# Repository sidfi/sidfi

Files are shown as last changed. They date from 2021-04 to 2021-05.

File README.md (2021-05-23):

# SIDfi

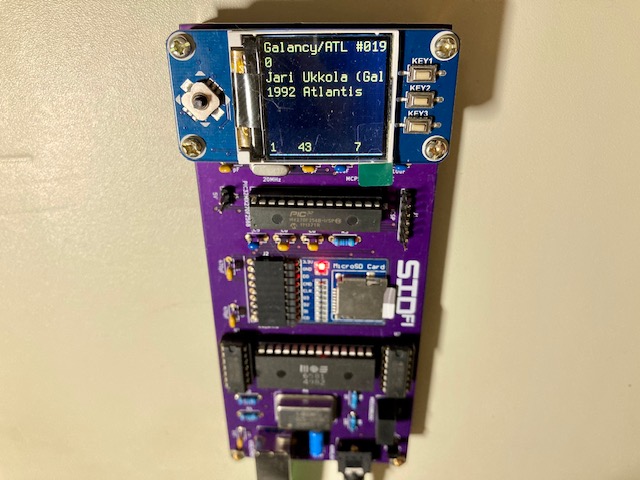
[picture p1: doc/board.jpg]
Board


SIDfi is a single-board self-contained SID file player. SIDfi requires the original MOS 6581 chip or a pin-compatible replacement such as [ARMSID](https://www.nobomi.cz/8bit/armsid/index_en.php). SIDfi plays tune files such as [High Voltage SID Collection](https://hvsc.c64.org/) from a FAT-formatted memory card and displays current tune information on a small LCD screen. Buttons on the LCD screen can be used to control the playback.

## Design Notes

- Emulates MOS 6502 on PIC32MX270F256 microcontroller using [MOS6502 library](https://github.com/gianlucag/mos6502);
- Firmware built with Microchip MPLAB v5.45 and XC32 v2.50;
- [Waveshare 1.44inch LCD HAT](https://www.waveshare.com/1.44inch-lcd-hat.htm) and [ST7735S library](https://github.com/bersch/ST7735S) for display and control;
- [Waveshare Micro SD Storage Board](https://www.waveshare.com/micro-sd-storage-board.htm) and [FatFs library](http://www.elm-chan.org/fsw/ff/00index_e.html) for memory card support;
- 2N3904 transistor for audio amplifier;
- Standard 3mm headset jack for audio output;
- USB 2.0 Type-B connector for 5V power supply (consumes 300mA).

## Schematics

Schematics

## PCB rendering

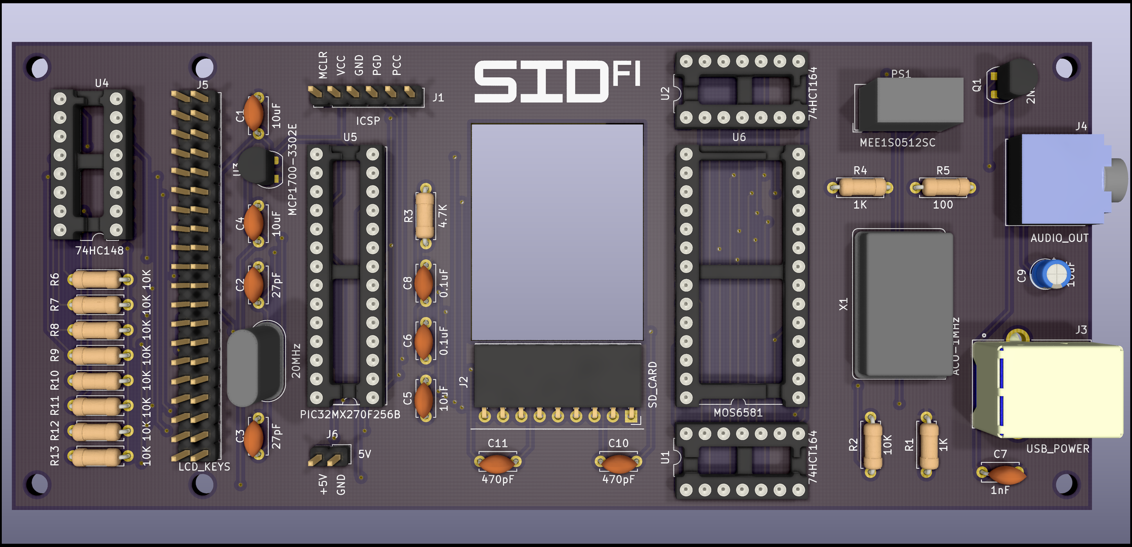
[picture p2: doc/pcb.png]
PCB


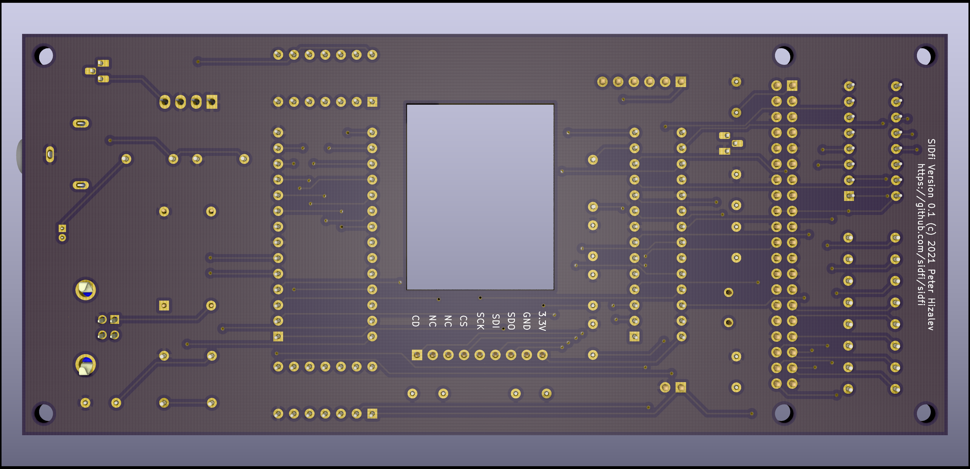
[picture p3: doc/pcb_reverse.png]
PCB reverse


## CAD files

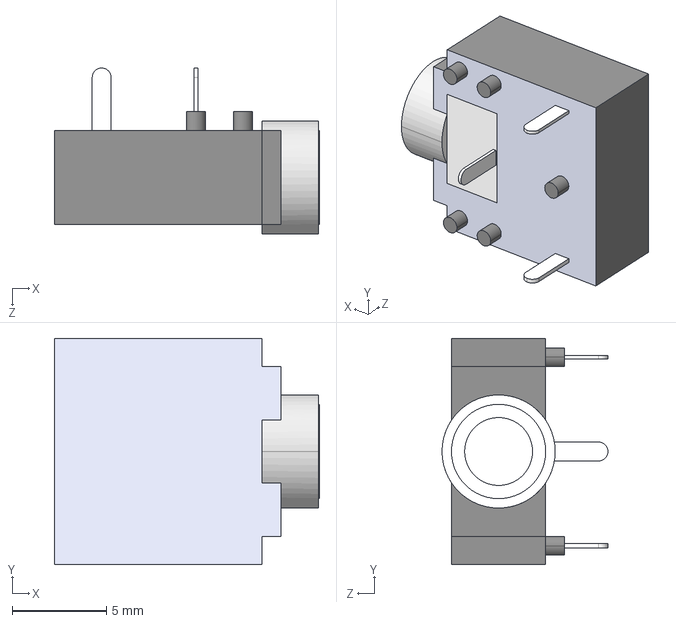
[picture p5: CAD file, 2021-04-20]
hardware/sidfi/3d/CUI_DEVICES_SJ1-3523NG.step
14.0 x 12.0 x 8.80 mm

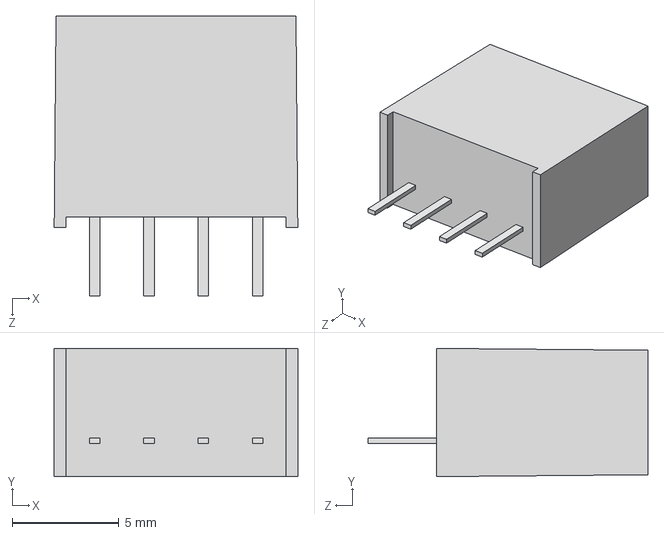
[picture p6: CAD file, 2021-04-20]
hardware/sidfi/3d/tme_3d_drawing.stp
11.4 x 6.00 x 13.1 mm
TME Series
TME PIN x 4

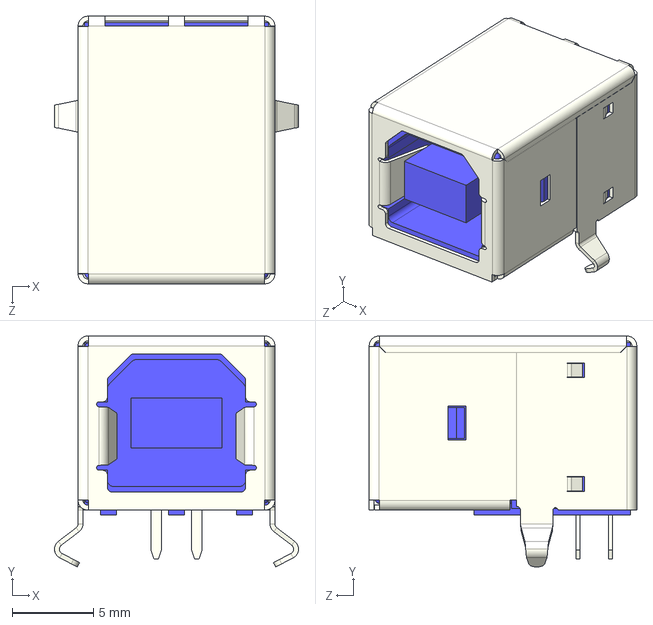
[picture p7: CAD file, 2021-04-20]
hardware/sidfi/3d/CUI_DEVICES_UJ2-BH-BL1-TH.step
15.0 x 14.2 x 16.5 mm

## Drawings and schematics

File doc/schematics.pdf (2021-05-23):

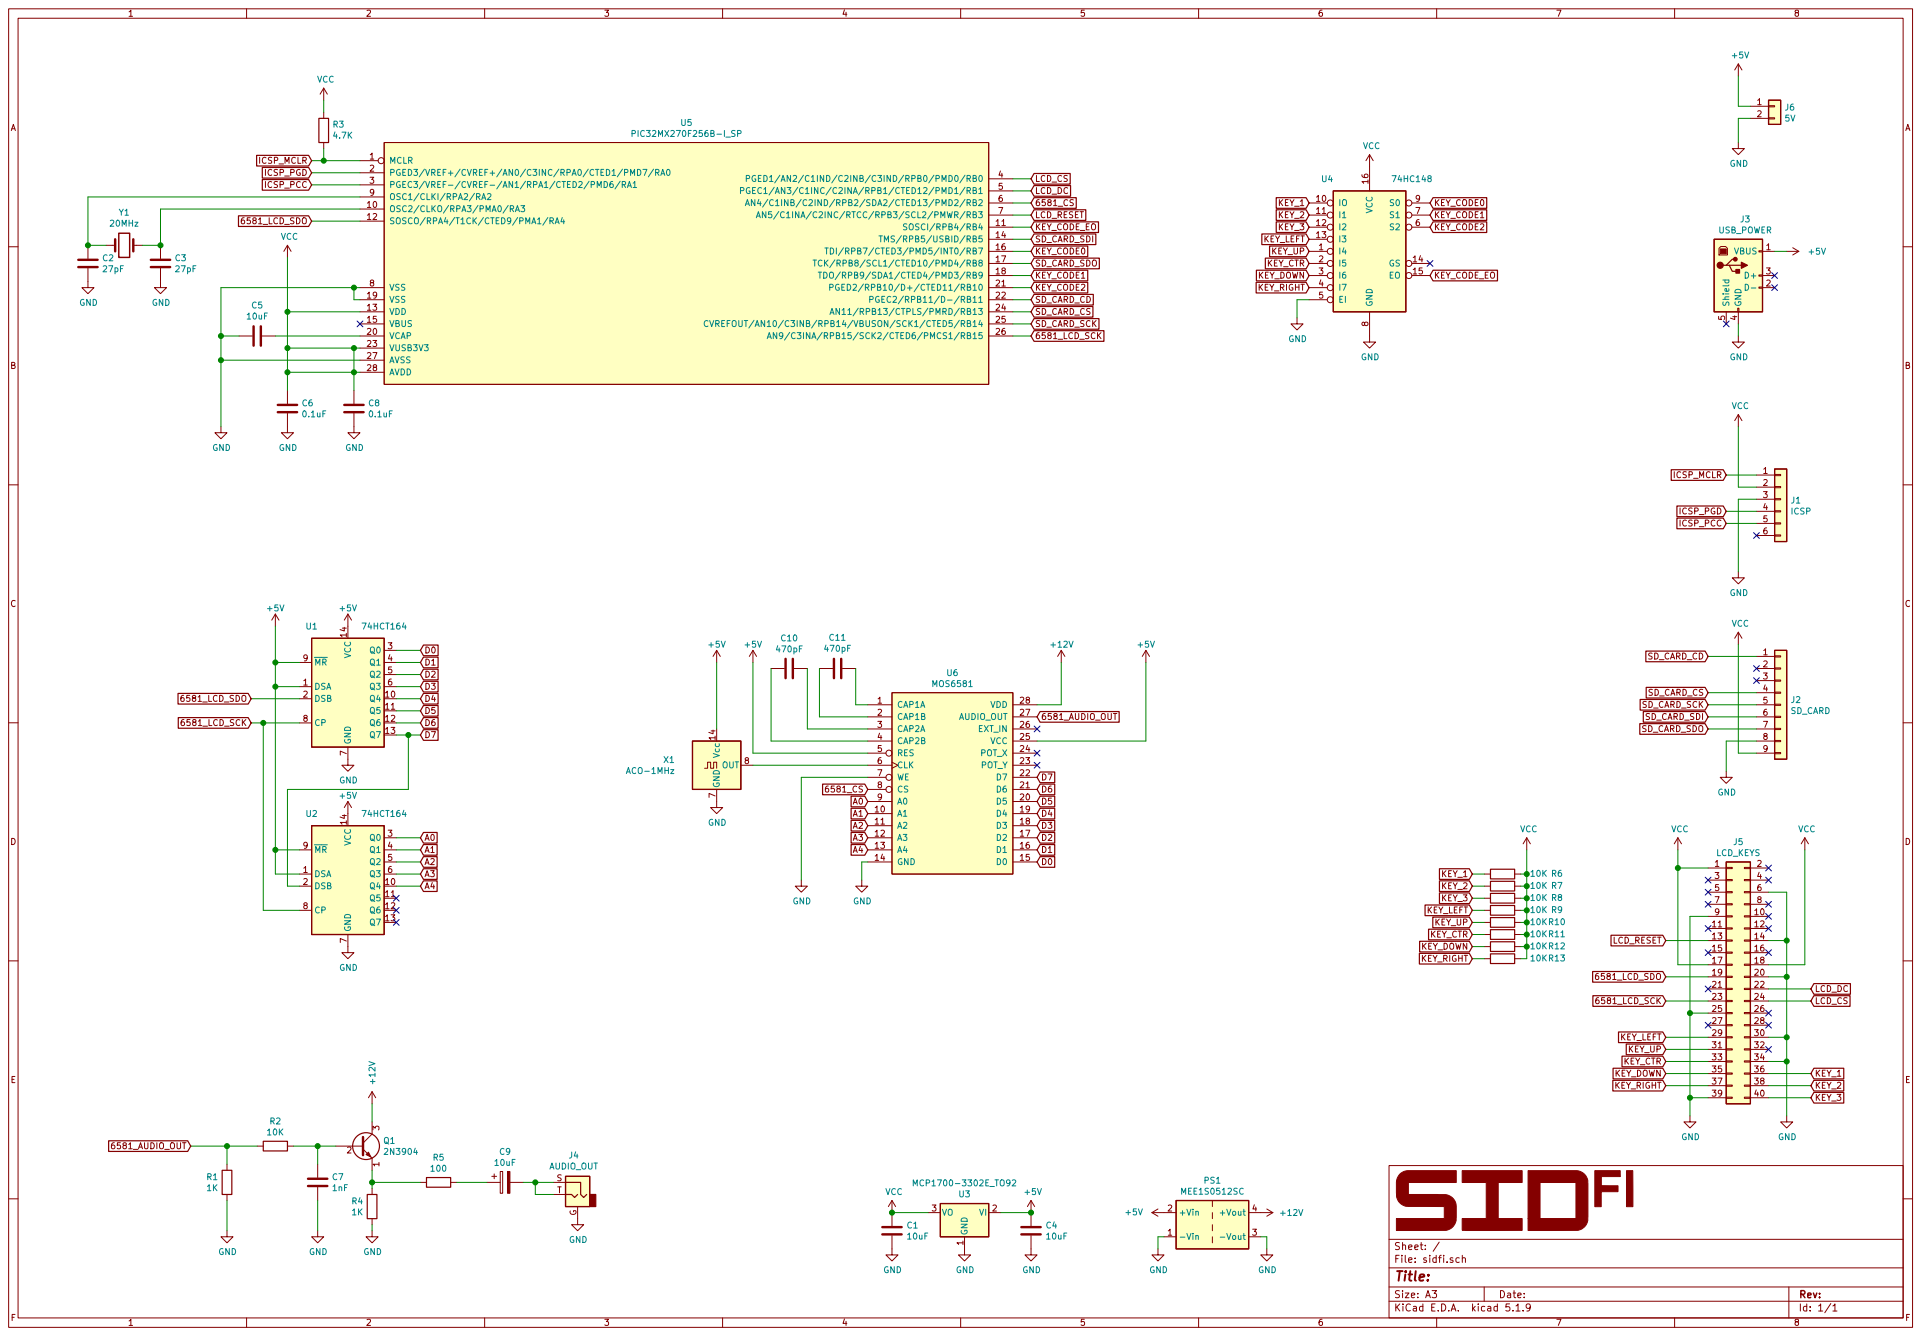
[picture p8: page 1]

7 OUT X1 8 ACO-1MHz GND GND

7 CP 8 MR 9U1 74HCT164 CAP1A 1 A1 10 A2 11 A3 12 A4 13 GND 14 D0 15 D1 16 D2 17 D3 18 D4 19 CAP1B 2 D5 20 D6 21 D7 22 POT_Y 23 POT_X 24 VCC 25 EXT_IN 26 AUDIO_OUT 27 VDD 28 CAP2A 3 CAP2B 4 RES 5 CLK 6 WE 7 CS 8 A0 9 U6 MOS6581

Id: 1/1 Title: File: sidfi.sch Sheet: / G

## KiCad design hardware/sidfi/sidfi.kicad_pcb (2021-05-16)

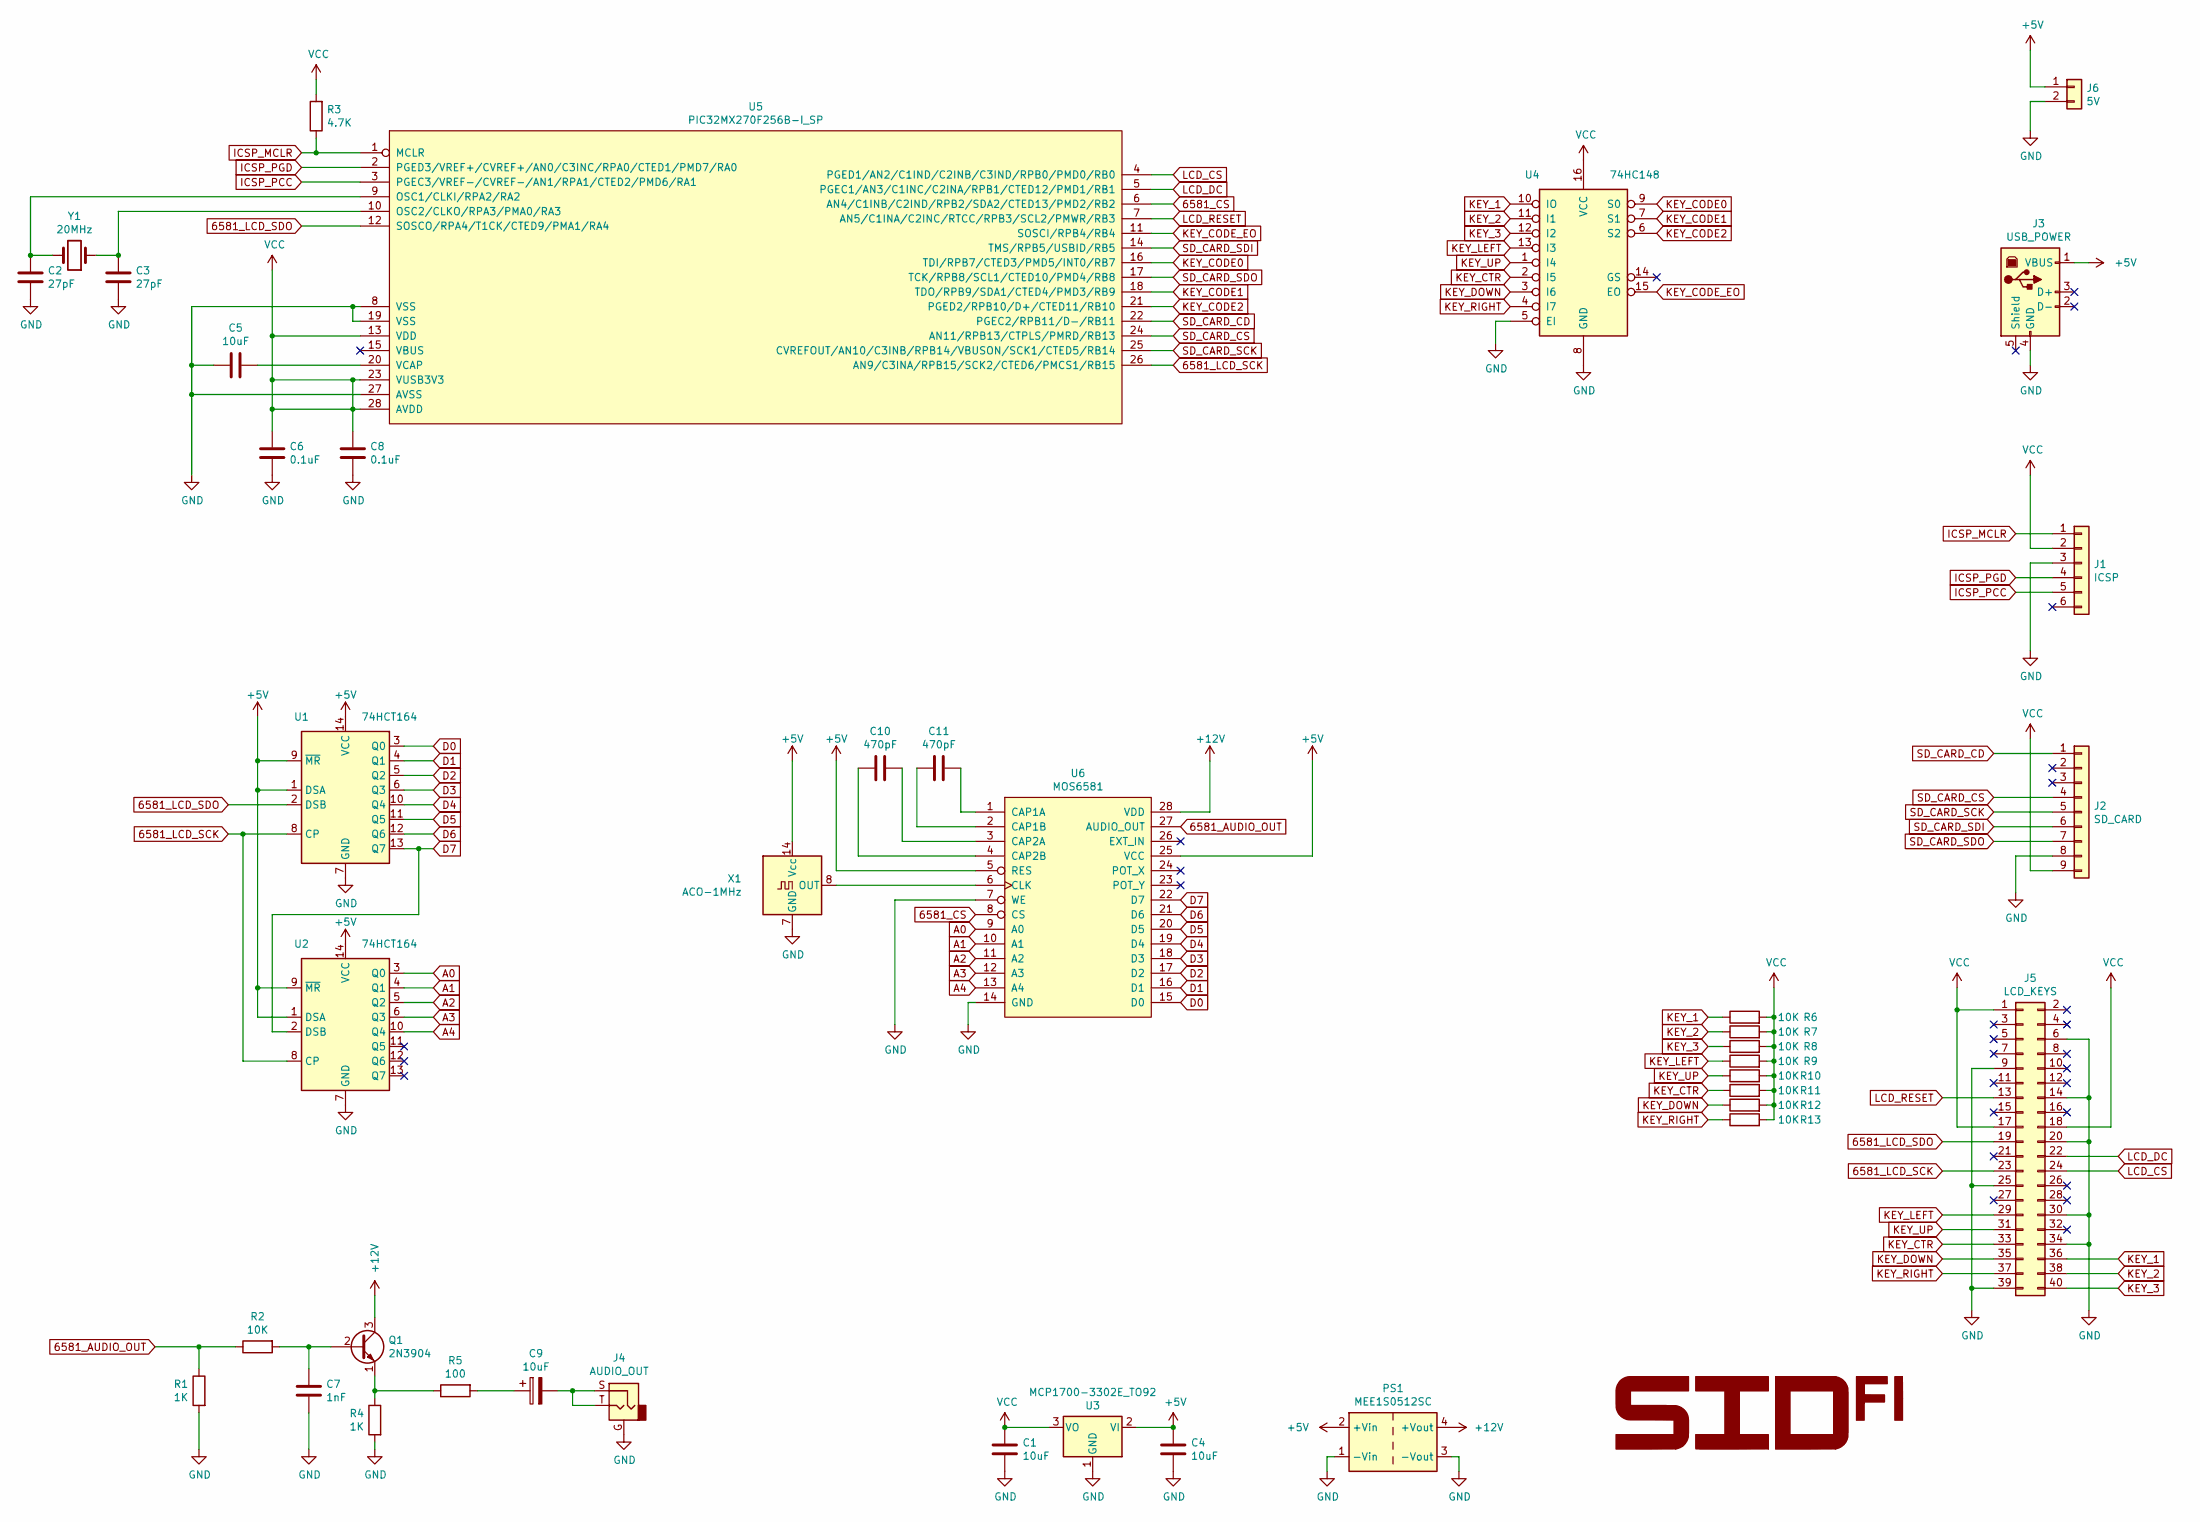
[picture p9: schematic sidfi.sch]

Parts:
C1, C4, C5: 10uF; C_Disc_D5.0mm_W2.5mm_P5.00mm
C2, C3: 27pF; C_Disc_D5.0mm_W2.5mm_P5.00mm
C6, C8: 0.1uF; C_Disc_D5.0mm_W2.5mm_P5.00mm
C7: 1nF; C_Disc_D5.0mm_W2.5mm_P5.00mm
C9: 10uF; CP_Radial_D4.0mm_P1.50mm
C10, C11: 470pF; C_Disc_D5.0mm_W2.5mm_P5.00mm
J1: ICSP; PinHeader_1x06_P2.54mm_Vertical
J2: SD_CARD; PinSocket_1x09_P2.54mm_Horizontal
J3: USB_POWER; CUI_UJ2-BH-1-TH
J4: AUDIO_OUT; CUI_SJ1-3523NG
J5: LCD_KEYS; PinHeader_2x20_P2.54mm_Vertical
J6: 5V; PinHeader_1x02_P2.54mm_Vertical
PS1: MEE1S0512SC; Converter_DCDC_Murata_MEE1SxxxxSC_THT
Q1: 2N3904; TO-92_HandSolder
R1, R4: 1K; R_Axial_DIN0207_L6.3mm_D2.5mm_P7.62mm_Horizontal
R2, R6, R7, R8, R9, R10, R11, R12, R13: 10K; R_Axial_DIN0207_L6.3mm_D2.5mm_P7.62mm_Horizontal
R3: 4.7K; R_Axial_DIN0207_L6.3mm_D2.5mm_P7.62mm_Horizontal
R5: 100; R_Axial_DIN0207_L6.3mm_D2.5mm_P7.62mm_Horizontal
U1, U2: 74HCT164; DIP-14_W7.62mm
U3: MCP1700-3302E_TO92; TO-92_HandSolder
U4: 74HC148; DIP-16_W7.62mm
U5: PIC32MX270F256B-I_SP; DIP-28_W7.62mm_Socket
U6: MOS6581; DIP-28_W15.24mm
X1: ACO-1MHz; Oscillator_DIP-14
Y1: 20MHz; Crystal_HC49-U_Vertical

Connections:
6581_AUDIO_OUT: R1.1, R2.1, U6.27 (AUDIO_OUT)
6581_CS: U5.6 (AN4/C1INB/C2IND/RPB2/SDA2/CTED13/PMD2/R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), U6.8 (CS)
6581_LCD_SCK: J5.23, U1.8 (CP), U2.8 (CP), U5.26 (AN9/C3INA/RPB15/SCK2/CTED6/PMCS1/RB15)
6581_LCD_SDO: J5.19, U1.2 (DSB), U5.12 (SOSCO/RPA4/T1CK/CTED9/PMA1/RA4)
+5V: C4.1, J3.1 (VBUS), J6.1, PS1.2 (+Vin), U1.1 (DSA), U1.9 (~MR), U1.14 (VCC), U2.1 (DSA), U2.9 (~MR), U2.14 (VCC), U3.2 (VI), U6.5 (RES), U6.25 (VCC), X1.14 (Vcc)
+12V: PS1.4 (+Vout), Q1.3 (C), U6.28 (VDD)
A0: U2.3 (Q0), U6.9 (A0)
A1: U2.4 (Q1), U6.10 (A1)
A2: U2.5 (Q2), U6.11 (A2)
A3: U2.6 (Q3), U6.12 (A3)
A4: U2.10 (Q4), U6.13 (A4)
D0: U1.3 (Q0), U6.15 (D0)
D1: U1.4 (Q1), U6.16 (D1)
D2: U1.5 (Q2), U6.17 (D2)
D3: U1.6 (Q3), U6.18 (D3)
D4: U1.10 (Q4), U6.19 (D4)
D5: U1.11 (Q5), U6.20 (D5)
D6: U1.12 (Q6), U6.21 (D6)
D7: U1.13 (Q7), U2.2 (DSB), U6.22 (D7)
GND: C1.2, C2.2, C3.2, C4.2, C5.2, C6.2, C7.2, C8.2, J1.3, J2.8, J3.4 (GND), J4.G, J5.6, J5.9, J5.14, J5.20, J5.25, J5.30, J5.34, J5.39, J6.2, PS1.1 (-Vin), PS1.3 (-Vout), R1.2, R4.2, U1.7 (GND), U2.7 (GND), U3.1 (GND), U4.5 (EI), U4.8 (GND), U5.8 (VSS), U5.19 (VSS), U5.27 (AVSS), U6.7 (WE), U6.14 (GND), X1.7 (GND)
ICSP_MCLR: J1.1, R3.1, U5.1 (MCLR)
ICSP_PCC: J1.5, U5.3 (PGEC3/VREF-/CVREF-/AN1/RPA1/CTED2/PMD6/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)
ICSP_PGD: J1.4, U5.2 (PGED3/VREF+/CVREF+/AN0/C3INC/RPA0/CTED1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)
KEY_1: J5.36, R6.1, U4.10 (IO)
KEY_2: J5.38, R7.1, U4.11 (I1)
KEY_3: J5.40, R8.1, U4.12 (I2)
KEY_CODE0: U4.9 (S0), U5.16 (TDI/RPB7/CTED3/PMD5/INT0/RB7)
KEY_CODE1: U4.7 (S1), U5.18 (TDO/RPB9/SDA1/CTED4/PMD3/RB9)
KEY_CODE2: U4.6 (S2), U5.21 (PGED2/RPB10/D+/CTED11/RB10)
KEY_CODE_EO: U4.15 (EO), U5.11 (SOSCI/RPB4/RB4)
KEY_CTR: J5.33, R11.1, U4.2 (I5)
KEY_DOWN: J5.35, R12.1, U4.3 (I6)
KEY_LEFT: J5.29, R9.1, U4.13 (I3)
KEY_RIGHT: J5.37, R13.1, U4.4 (I7)
KEY_UP: J5.31, R10.1, U4.1 (I4)
LCD_CS: J5.24, U5.4 (PGED1/AN2/C1IND/C2INB/C3IND/RPB0/PMD0/R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)
LCD_DC: J5.22, U5.5 (PGEC1/AN3/C1INC/C2INA/RPB1/CTED12/PMD1/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)
LCD_RESET: J5.13, U5.7 (AN5/C1INA/C2INC/RTCC/RPB3/SCL2/PMWR/RB3)
unnamed: C2.1, U5.9 (OSC1/CLKI/RPA2/RA2), Y1.2
unnamed: C3.1, U5.10 (OSC2/CLKO/RPA3/PMA0/RA3), Y1.1
unnamed: C5.1, U5.20 (VCAP)
unnamed: C7.1, Q1.2 (B), R2.2
unnamed: C9.1, R5.2
unnamed: C9.2, J4.S, J4.T
unnamed: C10.1, U6.3 (CAP2A)
unnamed: C10.2, U6.4 (CAP2B)
unnamed: C11.1, U6.2 (CAP1B)
unnamed: C11.2, U6.1 (CAP1A)
unnamed: Q1.1 (E), R4.1, R5.1
unnamed: U6.6 (CLK), X1.8 (OUT)
SD_CARD_CD: J2.1, U5.22 (PGEC2/RPB11/D-/RB11)
SD_CARD_CS: J2.4, U5.24 (AN11/RPB13/CTPLS/PMRD/RB13)
SD_CARD_SCK: J2.5, U5.25 (CVREFOUT/AN10/C3INB/RPB14/VBUSON/SCK1/C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)
SD_CARD_SDI: J2.6, U5.14 (TMS/RPB5/USBID/RB5)
SD_CARD_SDO: J2.7, U5.17 (TCK/RPB8/SCL1/CTED10/PMD4/RB8)
VCC: C1.1, C6.1, C8.1, J1.2, J2.9, J5.1, J5.17, J5.18, R3.2, R6.2, R7.2, R8.2, R9.2, R10.2, R11.2, R12.2, R13.2, U3.3 (VO), U4.16 (VCC), U5.13 (VDD), U5.23 (VUSB3V3), U5.28 (AVDD)

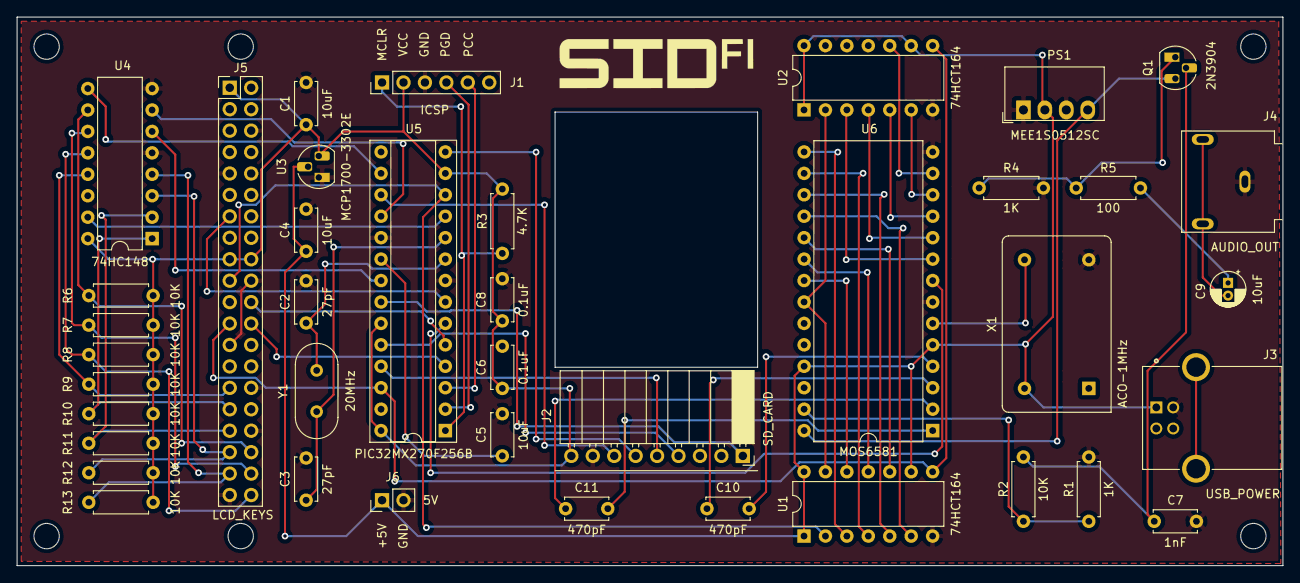
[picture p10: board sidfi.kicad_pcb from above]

Board: 2 copper layers, 150.0 x 65.0 mm, 40 parts (0 on the bottom side), 56 nets.

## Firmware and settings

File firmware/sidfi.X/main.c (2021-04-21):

#include "config.h"

#define _DISABLE_OPENADC10_CONFIGPORT_WARNING
#define _SUPPRESS_PLIB_WARNING
#include <plib.h>

#include <stdbool.h>
#include <stdint.h>
#include <stdlib.h>
#include <string.h>

#include "cpu.h"
#include "diskio.h"
#include "ff.h"
#include "st7735s.h"

#include "fonts.h"
#include "gfx.h"

#define CLOCKFREQ (50000000ul)  // This is set in in Configuration Bits.h
#define BUSFREQ (CLOCKFREQ / 1) // This is set in in Configuration Bits.h

#define nsleep(ns)                                                             \
  {                                                                            \
    uint32_t c =                                                               \
        ReadCoreTimer() + (((uint32_t)(ns)) / (2000000000 / CLOCKFREQ));       \
    while (ReadCoreTimer() < c)                                                \
      ;                                                                        \
  }
#define halt()                                                                 \
  {                                                                            \
    while (1)                                                                  \
      ;                                                                        \
  }

#define MEMORY_VIRTUAL_PAGE_NUMBER 64
#define MEMORY_PHYSICAL_PAGE_NUMBER 48
#define MEMORY_PAGE_SIZE 1024
#define MEMORY_PAGE_BITS 10
#define MEMORY_PAGE_MASK 0x3ff
#define MEMORY_UNALLOCATED_PAGE_NUMBER UINT16_MAX

uint16_t memory_page_table[MEMORY_VIRTUAL_PAGE_NUMBER];
uint8_t memory[MEMORY_PHYSICAL_PAGE_NUMBER * MEMORY_PAGE_SIZE];
uint8_t memory_free_page = 0;

void memory_init() {
  for (size_t i = 0; i < MEMORY_VIRTUAL_PAGE_NUMBER; ++i)
    memory_page_table[i] = MEMORY_UNALLOCATED_PAGE_NUMBER;
}

static bool memory_virtual_to_physical(uint16_t v_address,
                                       uint16_t *p_address) {
  size_t i = v_address >> MEMORY_PAGE_BITS;
  size_t p = memory_page_table[i];

  if (p == MEMORY_UNALLOCATED_PAGE_NUMBER) {
    if (memory_free_page == MEMORY_PHYSICAL_PAGE_NUMBER)
      return false;

    memory_page_table[i] = p = memory_free_page;
    memory_free_page++;
  }

  *p_address = (p << MEMORY_PAGE_BITS) | (v_address & MEMORY_PAGE_MASK);
  return true;
}

static bool memory_write(uint16_t address, uint8_t data) {
  bool res = memory_virtual_to_physical(address, &address);
  if (res)
    memory[address] = data;
  return res;
}

static uint8_t memory_read(uint16_t address) {
  bool res = memory_virtual_to_physical(address, &address);
  return res ? memory[address] : 0;
}

static bool is_mos6581_address(uint16_t address) {
  return address >= 0xD400 && address < 0xD800;
}

static void mos6581_write(uint8_t address, uint8_t data) {
  SPI2BUF = address;
  while (SPI2STATbits.SPIBUSY)
    ;

  SPI2BUF = data;
  while (SPI2STATbits.SPIBUSY)
    ;

  _LATB2 = 0;
  nsleep(5000);
  _LATB2 = 1;
}

void cpu_memory_write(uint16_t address, uint8_t data) {
  if (is_mos6581_address(address)) {
    mos6581_write(address & 0x1f, data);
  } else {
    memory_write(address, data);
  }
}

uint8_t cpu_memory_read(uint16_t address) {
  if (is_mos6581_address(address)) {
    return 0;
  }

  return memory_read(address);
}

#define PSID_MIN_HEADER_LENGTH 118 // Version 1
#define PSID_MAX_HEADER_LENGTH 124 // Version 2

// Offsets of fields in header (all fields big-endian)
enum {
  PSID_MAGIC_ID = 0,   // 'PSID'
  PSID_VERSION = 4,    // 1 or 2
  PSID_LENGTH = 6,     // Header length
  PSID_LOAD = 8,       // C64 load address
  PSID_INIT = 10,      // C64 init routine address
  PSID_PLAY = 12,      // C64 replay routine address
  PSID_NUMBER = 14,    // Number of subsongs
  PSID_DEFSONG = 16,   // Main subsong number
  PSID_SPEED = 18,     // Speed flags (1 bit/song)
  PSID_NAME = 22,      // Module name (ISO Latin1 character set)
  PSID_AUTHOR = 54,    // Author name (dto.)
  PSID_COPYRIGHT = 86, // Copyright info (dto.)
  PSID_FLAGS = 118,    // Flags (only in version 2 header)
  PSID_RESERVED = 120
};

enum sid_result {
  SIDFILE_OK,
  SIDFILE_ERROR_IO,
  SIDFILE_ERROR_MALFORMED,
  SIDFILE_ERROR_TOOBIG
};

struct sid {
  const char *module_name;
  const char *author_name;
  const char *copyright_info;
  size_t num_of_songs;
  size_t first_song;
  uint16_t init_address;
  uint16_t play_address;
  uint16_t load_address;
  uint32_t speed_flags;
};

static uint16_t read_uint16(const uint8_t *data, uint16_t offset) {
  return (data[offset] << 8) | data[offset + 1];
}

static uint32_t read_uint32(const uint8_t *data, uint16_t offset) {
  return (data[offset] << 24) | (data[offset + 1] << 16) |
         (data[offset + 2] << 8) | data[offset + 3];
}

static bool is_header(const uint8_t *data) {
  uint32_t magic_id = read_uint32(data, PSID_MAGIC_ID);
  uint16_t version = read_uint16(data, PSID_VERSION);
  return magic_id == 0x50534944 && (version == 1 || version == 2);
}

#define SID_READ_BUFFER_SIZE 512
uint8_t sid_read_buffer[SID_READ_BUFFER_SIZE];

enum sid_result sid_read_file(struct sid *sid, const TCHAR *file_path) {
  FIL f;
  FRESULT fr = f_open(&f, file_path, FA_READ);
  if (fr != FR_OK) {
    return SIDFILE_ERROR_IO;
  }

  UINT read;
  static uint8_t sid_header[PSID_MAX_HEADER_LENGTH];
  fr = f_read(&f, sid_header, PSID_MAX_HEADER_LENGTH, &read);

  if (fr != FR_OK) {
    f_close(&f);
    return SIDFILE_ERROR_IO;
  }

  if (read < PSID_MIN_HEADER_LENGTH || !is_header(sid_header)) {
    f_close(&f);
    return SIDFILE_ERROR_MALFORMED;
  }

  sid->num_of_songs = read_uint16(sid_header, PSID_NUMBER);

  if (sid->num_of_songs == 0) {
    sid->num_of_songs = 1;
  }

  sid->first_song = read_uint16(sid_header, PSID_DEFSONG);
  if (sid->first_song) {
    sid->first_song--;
  }
  if (sid->first_song >= sid->num_of_songs) {
    sid->first_song = 0;
  }

  sid->init_address = read_uint16(sid_header, PSID_INIT);
  sid->play_address = read_uint16(sid_header, PSID_PLAY);
  sid->speed_flags = read_uint32(sid_header, PSID_SPEED);

  sid->module_name = (const char *)(sid_header + PSID_NAME);
  sid->author_name = (const char *)(sid_header + PSID_AUTHOR);
  sid->copyright_info = (const char *)(sid_header + PSID_COPYRIGHT);

  FSIZE_t dataOffset = read_uint16(sid_header, PSID_LENGTH);
  fr = f_lseek(&f, dataOffset);

  if (fr != FR_OK) {
    f_close(&f);
    return SIDFILE_ERROR_IO;
  }

  // Find load address

  sid->load_address = read_uint16(sid_header, PSID_LOAD);
  if (sid->load_address == 0) {
    uint8_t lo, hi;
    fr = f_read(&f, &lo, 1, &read);
    if (fr != FR_OK) {
      f_close(&f);
      return SIDFILE_ERROR_IO;
    }

    fr = f_read(&f, &hi, 1, &read);
    if (fr != FR_OK) {
      f_close(&f);
      return SIDFILE_ERROR_IO;
    }

    sid->load_address = (hi << 8) | lo;
  }

  if (sid->init_address == 0) {
    sid->init_address = sid->load_address;
  }

  size_t address = sid->load_address;

  do {
    fr = f_read(&f, sid_read_buffer, SID_READ_BUFFER_SIZE, &read);

    for (size_t i = 0; i < read; ++i) {
      if (!memory_write(address + i, sid_read_buffer[i]))
        return SIDFILE_ERROR_TOOBIG;
    }

    address += read;

    if (fr != FR_OK) {
      f_close(&f);
      return SIDFILE_ERROR_IO;
    }
  } while (read != 0);

  f_close(&f);
  return SIDFILE_OK;
}

#define SONG_LENGTHS_MAX 16

struct song_lengths {
  size_t num;
  uint32_t ms[SONG_LENGTHS_MAX];
};

#define SONG_LENGTHS_LINE_BUFFER_SIZE 2048

enum song_lengths_res {
  SONG_LENGTHS_FOUND,
  SONG_LENGTHS_NOT_FOUND,
  SONG_LENGTHS_ERROR_IO
};

enum song_lengths_parse_state {
  SONG_LENGTHS_PARSE_STATE_NONE,
  SONG_LENGTHS_PARSE_STATE_MINUTES,
  SONG_LENGTHS_PARSE_STATE_SECONDS,
  SONG_LENGTHS_PARSE_STATE_MS
};

void song_lengths_read_value(struct song_lengths *song_lengths, size_t i,
                             enum song_lengths_parse_state parse_state,
                             uint32_t parse_value) {
  switch (parse_state) {
  case SONG_LENGTHS_PARSE_STATE_MINUTES:
    song_lengths->ms[i] += parse_value * 60000;
    break;
  case SONG_LENGTHS_PARSE_STATE_SECONDS:
    song_lengths->ms[i] += parse_value * 1000;
    break;
  case SONG_LENGTHS_PARSE_STATE_MS:
    song_lengths->ms[i] += parse_value;
    break;
  }
}

#define SONG_LENGTHS_PARSE_VALUE_MAX_DIGITS 3

uint32_t song_lengths_parse_value(
    size_t k, uint32_t parse_digits[SONG_LENGTHS_PARSE_VALUE_MAX_DIGITS]) {
  uint16_t parse_value = 0;
  const uint32_t multiple[SONG_LENGTHS_PARSE_VALUE_MAX_DIGITS] = {1, 10, 100};
  for (size_t i = 0; i < k; i++) {
    parse_value += parse_digits[i] * multiple[k - i - 1];
  }
  return parse_value;
}

enum song_lengths_res
song_lengths_read_line(uint8_t *line, const TCHAR *sid_file_path,
                       struct song_lengths *song_lengths) {
  static int last_strcmp_res = -1;
  if (line[0] == ';') {
    last_strcmp_res = strcmp(&line[2], sid_file_path);
  } else if (last_strcmp_res == 0) {
    last_strcmp_res = -1;

    size_t l = strlen(line);
    size_t k = 0;

    enum song_lengths_parse_state parse_state = SONG_LENGTHS_PARSE_STATE_NONE;
    uint32_t parse_digits[SONG_LENGTHS_PARSE_VALUE_MAX_DIGITS];

    song_lengths->num = 0;
    song_lengths->ms[0] = 0;

    for (size_t i = 0; i < l; i++) {
      if (line[i] == '=') {
        parse_state = SONG_LENGTHS_PARSE_STATE_MINUTES;
        k = 0;
      } else if (parse_state == SONG_LENGTHS_PARSE_STATE_MINUTES &&
                 line[i] == ':') {
        song_lengths_read_value(song_lengths, song_lengths->num, parse_state,
                                song_lengths_parse_value(k, parse_digits));

        parse_state = SONG_LENGTHS_PARSE_STATE_SECONDS;
        k = 0;
      } else if (parse_state == SONG_LENGTHS_PARSE_STATE_SECONDS &&
                 line[i] == '.') {
        song_lengths_read_value(song_lengths, song_lengths->num, parse_state,
                                song_lengths_parse_value(k, parse_digits));

        parse_state = SONG_LENGTHS_PARSE_STATE_MS;
        k = 0;
      } else if (line[i] == ' ') {
        if (song_lengths->num == SONG_LENGTHS_MAX - 1)
          break;

        song_lengths_read_value(song_lengths, song_lengths->num, parse_state,
                                song_lengths_parse_value(k, parse_digits));
        song_lengths->num++;

        song_lengths->ms[song_lengths->num] = 0;

        parse_state = SONG_LENGTHS_PARSE_STATE_MINUTES;
        k = 0;
      } else if (line[i] >= '0' && line[i] <= '9' &&
                 k < SONG_LENGTHS_PARSE_VALUE_MAX_DIGITS) {
        parse_digits[k] = (line[i] - 0x30);
        k++;
      }
    }
    song_lengths_read_value(song_lengths, song_lengths->num, parse_state,
                            song_lengths_parse_value(k, parse_digits));
    song_lengths->num++;

    return SONG_LENGTHS_FOUND;
  }
  return SONG_LENGTHS_NOT_FOUND;
}

#define SONG_LENGTHS_READ_BUFFER_SIZE 512
uint8_t song_lengths_read_buffer[SONG_LENGTHS_READ_BUFFER_SIZE];

FIL song_lengths_file;

void song_lengths_open_file(const TCHAR *song_lengths_file_path) {
  f_open(&song_lengths_file, song_lengths_file_path, FA_READ);
}

enum song_lengths_res
song_lengths_find_in_file(const TCHAR *sid_file_path,
                       struct song_lengths *song_lengths) {
  static uint8_t line_buffer[SONG_LENGTHS_LINE_BUFFER_SIZE];
  static UINT read = 0;

  size_t i = 0;
  FRESULT fr;

  do {
    static size_t k = 0;
    while (k != read) {
      uint8_t c = song_lengths_read_buffer[k++];
      if (c == '\n' || c == '\r' || i == SONG_LENGTHS_LINE_BUFFER_SIZE - 1) {
        if (i == 0)
          continue;

        line_buffer[i] = 0;
        i = 0;

        if (song_lengths_read_line(line_buffer, sid_file_path, song_lengths) ==
            SONG_LENGTHS_FOUND)
          return SONG_LENGTHS_FOUND;
      } else
        line_buffer[i++] = c;
    }

    k = 0;
    fr = f_read(&song_lengths_file, song_lengths_read_buffer, SONG_LENGTHS_READ_BUFFER_SIZE, &read);
    if (fr != FR_OK)
      return SONG_LENGTHS_ERROR_IO;

  } while (read != 0);

  fr = f_lseek(&song_lengths_file, 0);

  if (fr != FR_OK)
    return SONG_LENGTHS_ERROR_IO;

  return SONG_LENGTHS_NOT_FOUND;
}

void sid_init_player(struct sid *sid, uint8_t song_number) {
  // install reset vector for microplayer (0x0000)
  memory_write(0xFFFD, 0x00);
  memory_write(0xFFFC, 0x00);

  // install IRQ vector for play routine launcher (0x0013)
  memory_write(0xFFFF, 0x00);
  memory_write(0xFFFE, 0x13);

  // install the micro player, 6502 assembly code
  memory_write(0x0000, 0xA9); // A = 0, load A with the song number
  memory_write(0x0001, song_number);

  memory_write(0x0002, 0x20);                     // jump sub to INIT routine
  memory_write(0x0003, sid->init_address & 0xFF); // lo addr
  memory_write(0x0004, (sid->init_address >> 8) & 0xFF); // hi addr

  memory_write(0x0005, 0x58); // enable interrupt
  memory_write(0x0006, 0xEA); // nop
  memory_write(0x0007, 0x4C); // jump to 0x0006
  memory_write(0x0008, 0x06);
  memory_write(0x0009, 0x00);

  memory_write(0x0013, 0xEA); // nop  //0xA9; // A = 1
  memory_write(0x0014, 0xEA); // nop //0x01;
  memory_write(0x0015, 0xEA); // 0x78 CLI
  memory_write(0x0016, 0x20); // jump sub to play routine
  memory_write(0x0017, sid->play_address & 0xFF);
  memory_write(0x0018, (sid->play_address >> 8) & 0xFF);
  memory_write(0x0019, 0xEA); // 0x58 SEI
  memory_write(0x001A, 0x40); // RTI: return from interrupt
}

uint32_t sid_song_speed_ns(struct sid *sid, uint8_t song_number) {
  return ((sid->speed_flags >> (song_number % 32)) & 1) ? 16666666 /* 60Hz */
                                                        : 20000000 /* 50Hz */;
}

void __ISR(_TIMER_4_VECTOR, ipl1auto) T4Interrupt(void) {
  disk_timerproc();

  mT4ClearIntFlag();
}

uint32_t next_random() {
  static uint32_t random = 0;
  random += ReadCoreTimer();
  return random;
}

static char traverse_files_buffer[1024];
static size_t traverse_files_dir_index = -1;
static DIR traverse_files_dirs[6];

static FRESULT traverse_files_open_dir() {
  FRESULT res;
  res = f_opendir(&traverse_files_dirs[traverse_files_dir_index + 1],
                  traverse_files_buffer); /* Open the directory */
  if (res != FR_OK)
    return res;

  traverse_files_dir_index++;

  return res;
}

static void traverse_files_close_dir() {
  f_closedir(&traverse_files_dirs[traverse_files_dir_index]);

  traverse_files_dir_index--;
}

static FRESULT traverse_files_next(char **path) {
  FRESULT res;
  FILINFO fno;
  static size_t slash_pos[6];

  if (traverse_files_dir_index == -1) {
    res = traverse_files_open_dir();

    if (res != FR_OK)
      return res;

    slash_pos[traverse_files_dir_index] = -1;

    return traverse_files_next(path);
  }

  if (slash_pos[traverse_files_dir_index] != -1) {
    traverse_files_buffer[slash_pos[traverse_files_dir_index]] = 0;
    slash_pos[traverse_files_dir_index] = -1;
  }

  res = f_readdir(&traverse_files_dirs[traverse_files_dir_index], &fno);
  if (res != FR_OK)
    return res;

  if (!fno.fname[0]) {
    traverse_files_close_dir();

    return traverse_files_next(path);
  }

  size_t l = strlen(traverse_files_buffer);
  slash_pos[traverse_files_dir_index] = l;

  traverse_files_buffer[l] = '/';
  strcpy(&traverse_files_buffer[l + 1], fno.fname);

  if (fno.fattrib & AM_DIR) {
    res = traverse_files_open_dir();

    if (res != FR_OK)
      return res;

    slash_pos[traverse_files_dir_index] = -1;

    return traverse_files_next(path);
  }

  *path = traverse_files_buffer;
  return res;
}

static void traverse_files_init(const char *base_path) {
  while (traverse_files_dir_index != -1) {
    f_closedir(&traverse_files_dirs[traverse_files_dir_index]);
    traverse_files_dir_index--;
  }

  strcpy(traverse_files_buffer, base_path);
}

static uint32_t break_timer0 = 0;
static uint32_t break_timer1 = 0;

static bool set_break_ns(uint32_t ns0, uint32_t ns1) {
  break_timer0 = ns0 / (2000000000 / CLOCKFREQ);
  break_timer1 = ns1 / (2000000000 / CLOCKFREQ);
  WriteCoreTimer(0);
}

static bool should_break0() { return ReadCoreTimer() >= break_timer0; }
static bool should_break1() { return ReadCoreTimer() >= break_timer1; }

char *itoa(int value) {
  static char buffer[12]; // 12 bytes is big enough for an INT32
  int original = value;   // save original value

  int c = sizeof(buffer) - 1;

  buffer[c] = 0; // write trailing null in last byte of buffer

  if (value < 0) // if it's negative, note that and take the absolute value
    value = -value;

  do // write least significant digit of value that's left
  {
    buffer[--c] = (value % 10) + '0';
    value /= 10;
  } while (value);

  if (original < 0)
    buffer[--c] = '-';

  return &buffer[c];
}

static FATFS fs;

#define SCANCODE_NONE 7
#define SCANCODE_RIGHT 8
#define SCANCODE_LEFT 9
#define SCANCODE_CTR 10
#define SCANCODE_KEY2 11
#define SCANCODE_DOWN 12
#define SCANCODE_KEY1 13
#define SCANCODE_UP 14
#define SCANCODE_KEY3 15

int main() {
  ANSELA = 0;
  ANSELB = 0;
  mJTAGPortEnable(0);

  SYSTEMConfigPerformance(CLOCKFREQ);
  mOSCSetPBDIV(OSC_PB_DIV_1);

  LATA = LATB = 0;
  TRISA = TRISB = 0xffffffff;
  CNENA = CNENB = CNCONA = CNCONB = 0;
  CNPUA = CNPUB = CNPDA = CNPDB = 0;

  PR4 = 1000 * (BUSFREQ / 2 / 1000000) - 1;
  T4CON = 0x8010;
  mT4SetIntPriority(1);
  mT4ClearIntFlag();
  mT4IntEnable(1);

  _TRISB2 = 0; _LATB2 = 1;  // MOS 6581 CS        (6)
  PPSOutput(3, RPA4, SDO2); // MOS 6581 / LCD SDO (12)
                            // MOS 6581 / LCD SCK (26)

  _TRISB13 = 0; _LATB13 = 1; // SD CARD CS  (24)
  _TRISB11 = 1;              // SD CARD CD  (22)
  PPSOutput(2, RPB5, SDO1);  // SD CARD SDO (14)
  PPSInput(2, SDI1, RPB8);   // SD CARD SDI (17)
                             // SD CARD SCK (25)

  _TRISB0 = 0; _LATB0 = 1; // LCD CS    (4)
  _TRISB1 = 0; _LATB1 = 1; // LCD DC    (5)
  _TRISB3 = 0; _LATB3 = 0; // LCD RESET (7)

  _TRISB4 = 1;  // KEY CTR   (11)
  _TRISB7 = 1;  // KEY UP    (16)
  _TRISB9 = 1;  // KEY DOWN  (18)
  _TRISB10 = 1; // KEY RIGHT (21)

  INTEnableSystemMultiVectoredInt();
  INTEnableInterrupts();

  nsleep(1000000);

  SpiChnOpen(SPI_CHANNEL2,
             (SpiOpenFlags)(SPI_OPEN_MODE8 | SPI_OPEN_MSTEN | SPI_OPEN_DISSDI |
                            SPI_OPEN_CKE_REV),
             2);

  ST7735S_Init();
  setOrientation(R0);

  f_mount(&fs, "", 0);

  setbgColor(31, 63, 31);
  setFont(ter_u16n);

  memory_init();
  cpu_init(cpu_memory_read, cpu_memory_write);

  traverse_files_init("");
  song_lengths_open_file("/DOCUMENTS/Songlengths.md5");

  next_random();

  struct sid sid;
  struct song_lengths song_lengths;
  
  memset(&sid, 0, sizeof(struct sid));
  memset(&song_lengths, 0, sizeof(struct song_lengths));
  
  uint32_t timer = 0;
  uint8_t song_number = 0;
  uint32_t song_speed_ns = 0;
  uint32_t song_length_ms = 0;
  uint8_t debounce_counter = 0;
  uint8_t prev_scancode = 1;
  enum song_lengths_res slr = 0;

  while (1) {
    if (!timer) {
      if (!sid.num_of_songs || ++song_number == sid.num_of_songs) {
        setColor(31, 63, 31);
        fillScreen();
        setColor(0, 63, 0);
        drawText(0, 0, "Loading...");
        flushBuffer();

        while (1) {
          char *sid_file_path;
          FRESULT fr;
          uint32_t i = next_random() % 10000;          

          while (i--)
            fr = traverse_files_next(&sid_file_path);
            
          if (fr != FR_OK)
            continue;

          enum sid_result sidr = sid_read_file(&sid, sid_file_path);
          if (sidr == SIDFILE_OK) {
            slr = song_lengths_find_in_file(sid_file_path, &song_lengths);
            song_number = 0;
            break;
          }
        }
      }
      song_length_ms =
          ((slr == SONG_LENGTHS_FOUND && song_number < song_lengths.num)
               ? song_lengths.ms[song_number]
               : 60000);
      song_speed_ns = sid_song_speed_ns(&sid, song_number);
      timer = (song_length_ms * 1000) / (song_speed_ns / 1000);

      sid_init_player(&sid, song_number);

      set_break_ns(1000000, 0);
      cpu_reset();
      cpu_run(should_break0);

      setColor(31, 63, 31);
      fillScreen();
      setColor(0, 0, 31);
      uint16_t line = 0;
      /*size_t len = strlen(sid_file_path);
      for (size_t i = 0; i <= len / 16; i++)
        drawText(0, (line++) * 16, sid_file_path + (i * 16));*/
      drawText(0, (line++) * 16, sid.module_name);
      drawText(0, (line++) * 16, itoa(song_number));
      drawText(0, (line++) * 16, sid.author_name);
      drawText(0, (line++) * 16, sid.copyright_info);
      flushBuffer();
    } else
      timer--;

    set_break_ns(song_speed_ns - 4000000, song_speed_ns);
    cpu_irq();
    cpu_run(should_break0);

    uint8_t scancode = (_RB4 << 3) | (_RB7 << 2) | (_RB9 << 1) | _RB10;

    if (scancode != prev_scancode) {
      debounce_counter = 0;
      prev_scancode = scancode;
    } else
      debounce_counter++;

    if (debounce_counter == 3) {
      debounce_counter = 0;

      if (scancode == SCANCODE_KEY1) {
        timer = 0;
        continue;
      }
    }

    uint32_t seconds = (timer * (song_speed_ns / 1000)) / 1000000;

    drawText(0, 112, itoa(seconds / 60));
    drawText(32, 112, itoa(seconds % 60));
    drawText(96, 112, itoa(scancode));
    flushBuffer();

    while (!should_break1())
      ;
  }

  return 0;
}

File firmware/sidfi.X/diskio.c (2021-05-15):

/*------------------------------------------------------------------------/
/  MMCv3/SDv1/SDv2+ (in SPI mode) control module
/-------------------------------------------------------------------------/
/
/  Copyright (C) 2014, ChaN, all right reserved.
/
/ * This software is a free software and there is NO WARRANTY.
/ * No restriction on use. You can use, modify and redistribute it for
/   personal, non-profit or commercial products UNDER YOUR RESPONSIBILITY.
/ * Redistributions of source code must retain the above copyright notice.
/
/-------------------------------------------------------------------------*/

#define _DISABLE_OPENADC10_CONFIGPORT_WARNING
#define _SUPPRESS_PLIB_WARNING
#include <plib.h>
#include "diskio.h"


/* Socket controls  (Platform dependent) */
#define CS_LOW()	_LATB13 = 0	/* MMC CS = L */
#define CS_HIGH()	_LATB13 = 1	/* MMC CS = H */
#define MMC_CD		(!_RB11)	/* Card detected   (yes:true, no:false, default:true) */
#define MMC_WP		0		/* Write protected (yes:true, no:false, default:false) */

/* SPI bit rate controls */

/* Set slow clock for card initialization (100k-400k) */
#define FCLK_SLOW()                                                                \
	SpiChnOpen(SPI_CHANNEL1,                                                       \
			   (SpiOpenFlags)(SPI_OPEN_MODE8 | SPI_OPEN_MSTEN | SPI_OPEN_CKE_REV), \
			   125);

/* Set fast clock for generic read/write */
#define FCLK_FAST()                                                                \
	SpiChnOpen(SPI_CHANNEL1,                                                       \
			   (SpiOpenFlags)(SPI_OPEN_MODE8 | SPI_OPEN_MSTEN | SPI_OPEN_CKE_REV), \
			   4);

/*--------------------------------------------------------------------------

   Module Private Functions

---------------------------------------------------------------------------*/

/* Definitions for MMC/SDC command */
#define CMD0   (0)			/* GO_IDLE_STATE */
#define CMD1   (1)			/* SEND_OP_COND */
#define ACMD41 (41|0x80)	/* SEND_OP_COND (SDC) */
#define CMD8   (8)			/* SEND_IF_COND */
#define CMD9   (9)			/* SEND_CSD */
#define CMD10  (10)			/* SEND_CID */
#define CMD12  (12)			/* STOP_TRANSMISSION */
#define ACMD13 (13|0x80)	/* SD_STATUS (SDC) */
#define CMD16  (16)			/* SET_BLOCKLEN */
#define CMD17  (17)			/* READ_SINGLE_BLOCK */
#define CMD18  (18)			/* READ_MULTIPLE_BLOCK */
#define CMD23  (23)			/* SET_BLOCK_COUNT */
#define ACMD23 (23|0x80)	/* SET_WR_BLK_ERASE_COUNT (SDC) */
#define CMD24  (24)			/* WRITE_BLOCK */
#define CMD25  (25)			/* WRITE_MULTIPLE_BLOCK */
#define CMD41  (41)			/* SEND_OP_COND (ACMD) */
#define CMD55  (55)			/* APP_CMD */
#define CMD58  (58)			/* READ_OCR */


static volatile
DSTATUS Stat = STA_NOINIT;	/* Disk status */

static volatile
UINT Timer1, Timer2;		/* 1000Hz decrement timer */

static
UINT CardType;



/*-----------------------------------------------------------------------*/
/* Interface Controls (Platform dependent)                               */
/*-----------------------------------------------------------------------*/
/* When the target system does not support socket power control, there   */
/* is nothing to do in these functions.                                  */

static
void power_on (void)
{
	;					/* Turn socket power on, delay >1ms (Nothing to do) */    
}

static
void power_off (void)
{
	;					/* Turn socket power off (Nothing to do) */
}



/*-----------------------------------------------------------------------*/
/* SPI Transactions (Platform dependent)                                 */
/*-----------------------------------------------------------------------*/

/* Single byte SPI transaction */
static
BYTE xchg_spi (BYTE dat)
{
	SPI1BUF = dat;			/* Initiate an SPI transaction */
	while (!SPI1STATbits.SPIRBF) ;		/* Wait for end of the SPI transaction */
	return (BYTE)SPI1BUF;	/* Get received byte */
}


/* Multi-byte SPI transaction (transmit) */
static
void xmit_spi_multi (
	const BYTE* buff,	/* Data to be sent */
	UINT cnt			/* Number of bytes to send */
)
{
	do {
		SPI1BUF = *buff++;	/* Initiate an SPI transaction */
		while (!SPI1STATbits.SPIRBF) ;	/* Wait for end of the SPI transaction */
		SPI1BUF;			/* Discard received byte */
		SPI1BUF = *buff++;
		while (!SPI1STATbits.SPIRBF) ;
		SPI1BUF;
	} while (cnt -= 2);
}


/* Multi-byte SPI transaction (receive) */
static
void rcvr_spi_multi (
	BYTE* buff,		/* Buffer to store received data */
	UINT cnt		/* Number of bytes to receive */
)
{
	do {
		SPI1BUF = 0xFF;		/* Initiate an SPI transaction */
		while (!SPI1STATbits.SPIRBF) ;	/* Wait for end of the SPI transaction */
		*buff++ = SPI1BUF;	/* Get received byte */
		SPI1BUF = 0xFF;
		while (!SPI1STATbits.SPIRBF) ;
		*buff++ = SPI1BUF;
	} while (cnt -= 2);
}



/*-----------------------------------------------------------------------*/
/* Wait for card ready                                                   */
/*-----------------------------------------------------------------------*/

static
int wait_ready (void)
{
	BYTE d;

	Timer2 = 500;	/* Wait for ready in timeout of 500ms */
	do {
		d = xchg_spi(0xFF);
	} while ((d != 0xFF) && Timer2);

	return (d == 0xFF) ? 1 : 0;
}



/*-----------------------------------------------------------------------*/
/* Deselect the card and release SPI bus                                 */
/*-----------------------------------------------------------------------*/

static
void deselect (void)
{
	CS_HIGH();			/* Set CS# high */
	xchg_spi(0xFF);		/* Dummy clock (force DO hi-z for multiple slave SPI) */
}



/*-----------------------------------------------------------------------*/
/* Select the card and wait ready                                        */
/*-----------------------------------------------------------------------*/

static
int select (void)	/* 1:Successful, 0:Timeout */
{
	CS_LOW();			/* Set CS# low */
	xchg_spi(0xFF);		/* Dummy clock (force DO enabled) */

	if (wait_ready()) return 1;	/* Wait for card ready */

	deselect();
	return 0;	/* Timeout */
}



/*-----------------------------------------------------------------------*/
/* Receive a data packet from MMC                                        */
/*-----------------------------------------------------------------------*/

static
int rcvr_datablock (	/* 1:OK, 0:Failed */
	BYTE *buff,			/* Data buffer to store received data */
	UINT btr			/* Byte count (must be multiple of 4) */
)
{
	BYTE token;


	Timer1 = 100;
	do {							/* Wait for data packet in timeout of 100ms */
		token = xchg_spi(0xFF);
	} while ((token == 0xFF) && Timer1);

	if(token != 0xFE) return 0;		/* If not valid data token, retutn with error */

	rcvr_spi_multi(buff, btr);		/* Receive the data block into buffer */
	xchg_spi(0xFF);					/* Discard CRC */
	xchg_spi(0xFF);

	return 1;						/* Return with success */
}
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

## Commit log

2021-04-19 CUI footprints
2021-04-20 Fix crash when OOM on writing
    [main.c]
2021-04-20 Route the PCB
    [CUI_DEVICES_SJ1-3523NG.step, CUI_DEVICES_UJ2-BH-BL1-TH.step, sidfi.kicad_pcb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]
2021-04-20 3D render the PCB
2021-04-20 Remove accidental objects in PCB
    [sidfi.kicad_pcb]
2021-04-21 Adjust audio connector footprint
    [sidfi.kicad_pcb]
2021-04-22 Logo. Redo PCB.
    [sidfi.kicad_pcb, sidfi.sch]
2021-05-15 PCB fixes
    [sidfi.kicad_pcb]
2021-05-15 Adjust for Waveshare SD storage board
2021-05-16 Label pins on J1 and J6
    [sidfi.kicad_pcb]
2021-05-23 Update PCB rendeing

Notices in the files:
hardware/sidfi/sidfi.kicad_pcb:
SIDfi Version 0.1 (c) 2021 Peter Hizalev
